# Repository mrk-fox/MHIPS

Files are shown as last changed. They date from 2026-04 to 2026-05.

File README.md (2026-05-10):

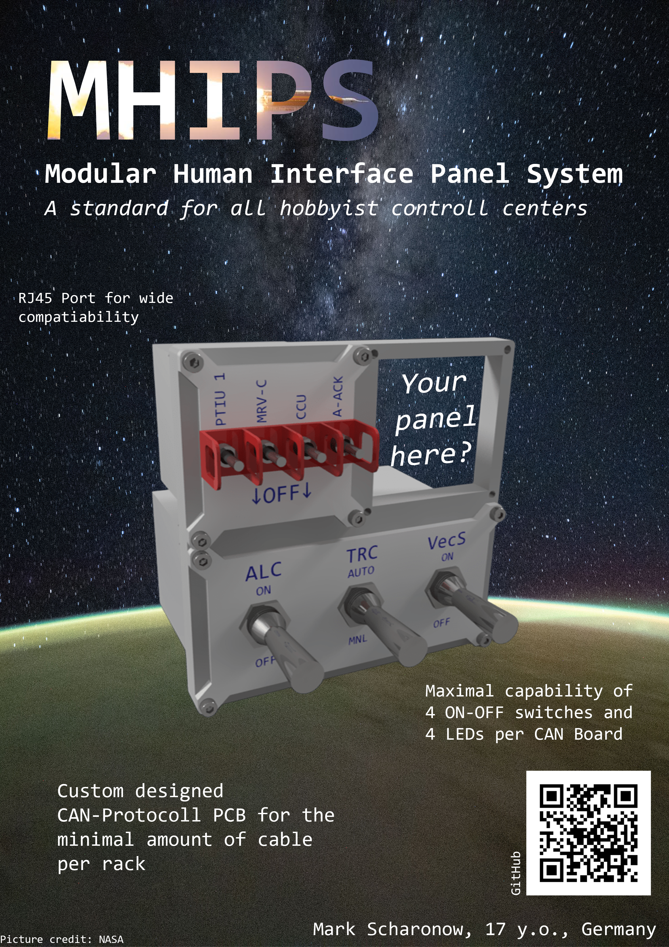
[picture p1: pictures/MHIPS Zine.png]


<h1 align="center">MHIPS</h1>
<div align="center">Modular Human Interface Panels System</div>
<br>
<div align="center">
      
 



</div>
<br>

<br> <br>
# Introduction
As controlling any type of craft with electronical components reqiring human intervention to function grows with the complexity of the craft and its tasks, I have decided to design a controlling system which is modular and uses near-aerospace-safety protocolls.

**Please pay attention to the fact that this project is still being developed. There is no "final solution" or such similar.**

## Functionality and goals

Every sucesfull project resembles a solution for a problem. Thus, the problem needs to be formulated before a solution is deigned. The problem that this project solves is the complexity of digital menus and the lack of haptic response in controlling anything with pure software.
My solution is a _modular, standartized panel system_ 
Hence, a ruleset was reqired to ensure the mulitcompatiability and extensiabiliy of this project.

### Why is it unique?
A central question in research, engineering and most other fields is "why has nobody done this before". Well, there are solutions to thes problem. Even one NASA provides in their GitHub repositories. But all of them are way to professional for amateur/non-professional use.

### Why did i make it?
Well, I'm planning on buiding an autonomous portable UAV someday. One day. Maybe. So these can be the GCC controls.

# Standartization

In this section we define a convention for the MHIPS (Modular Human Interface Panel System).
``` 
1. The abbreviation "MHIPS" stands for "Modular Human Interface Panel System".
      a. A panel is defined as a mounted and rigid resembly of multiple tiles, solving a user-defined task.
      b. A tile is defined as the smallest unit of the system. Any tile consists of the following components:
           b.1. A CAN-Capable read-write PCB as the BusPlate.
           b.2. A casing consisting of the front case and the backplate
           b.3. Input and output elements as Light Emitting Diodes, Buttons, Switches and more mounted into the front plate of the casing
      c. A rack is defined as the structure carrying and spacing the tiles.
2. The basic structure for a rack is a 5mm wide frame with the inner sizing of 50x50mm and a thickness of minimum 4mm. By fusing such frames togoether a rack is built. Each basic frame resembles the size of one unit (1U).
3. We define three levels of controll elements protection to ensure a dynamic range of application and environemntal adaptation.
      a. A level 3 tile is defined as a tile with no switch protection against accidental action.
      b. A level 2 tile is defined as a tile with sufficient control elements protection to ensure protection against accidental action. Only fully contacted switches (e.g.       ON-ON) are allowed.
      c. A level 1 tile is defined as a tile with maximal protection against accidental action. Double action is the minimum requirement. We split the level 1 category in the following subgroups:
            c.1. A level 1-S tile is definied as a tile meeting the basic level 1 requirements and the additional requirement of the maxiaml control element density of one control element per rack unit.
            c.2. A level 1-HV tile is definied as a tile meeting the basic level 1 requirements and additionally having the front tile face colored in a high visiability pattern (e.g. black and yellow stripes, 15mm wide at a 45° angle to the bottom plate of the tile) and having a maxiaml control element density of one control element per rack unit.
```
The given standartization is applied to all the racks and tiles in this current project.

# Example solution
In the following secion I will present my solution for the standartization and problem.

## BusPlate
The core piece of the work is the BusPlate resembling a PCB with the following features:

- RP2040 controller
- USB-C connectivity
- CAN Bus feature with MCP2515 controller
- Power and data over RJ45
- Decentralized computing capability on board

The following pictures are the front and back of the BusPlate PCB.

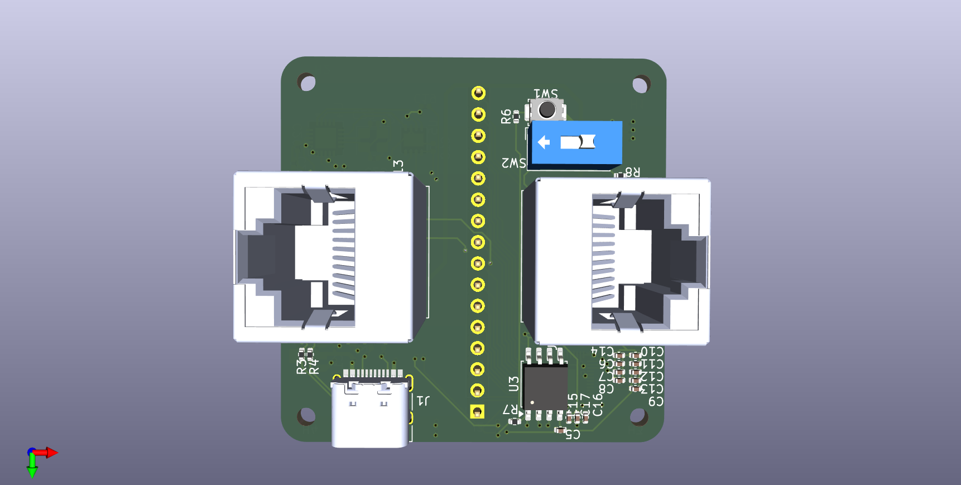
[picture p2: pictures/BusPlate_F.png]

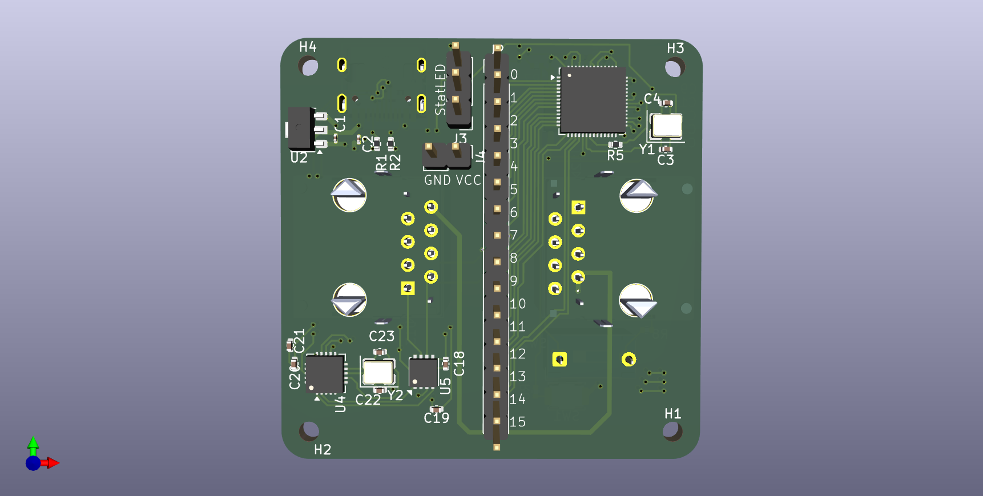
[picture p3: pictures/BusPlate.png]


The following diagram shows the schematics for this PCB created in KiCad.

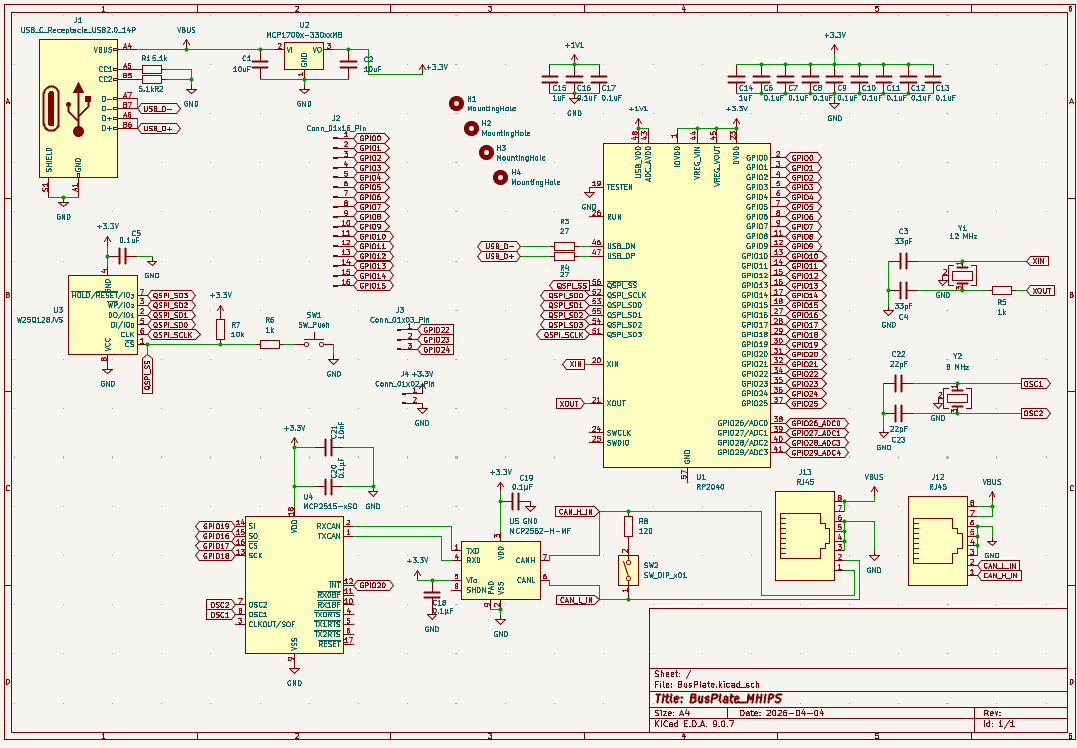
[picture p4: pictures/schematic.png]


The following picures are the single PCB layers in the order "Front, In 1, In 2, Back"

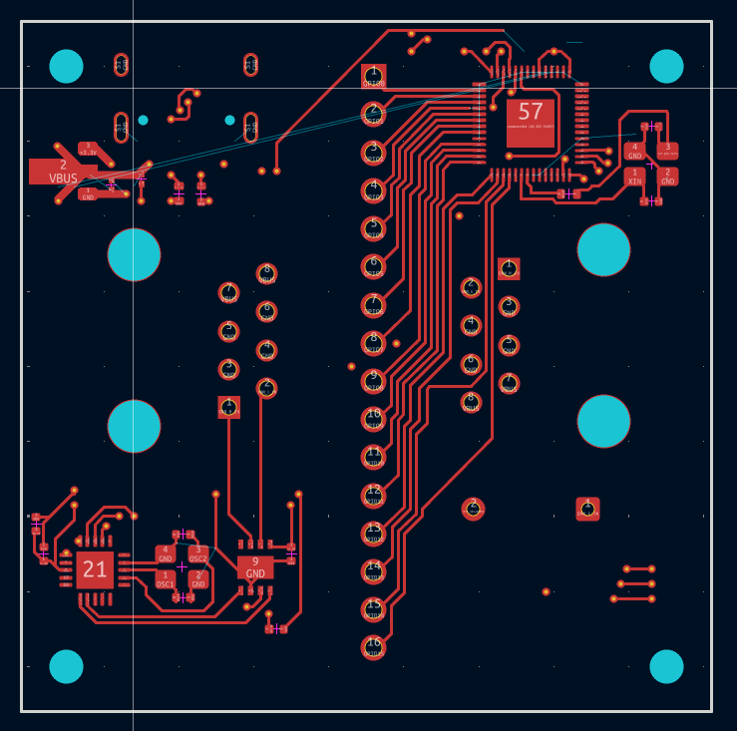
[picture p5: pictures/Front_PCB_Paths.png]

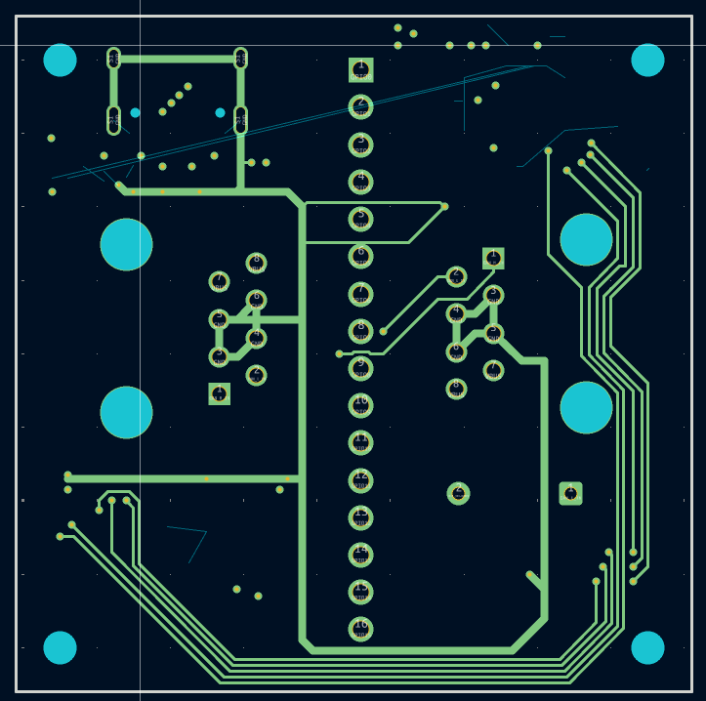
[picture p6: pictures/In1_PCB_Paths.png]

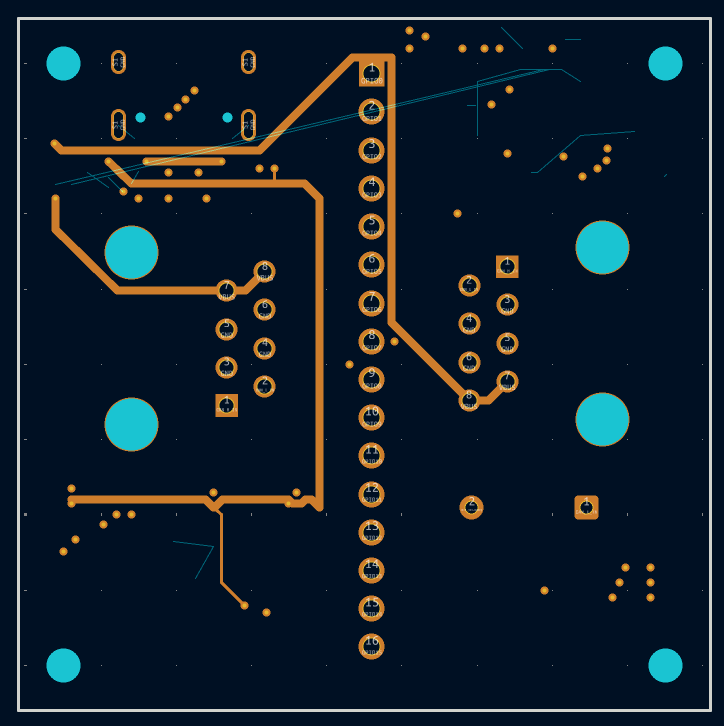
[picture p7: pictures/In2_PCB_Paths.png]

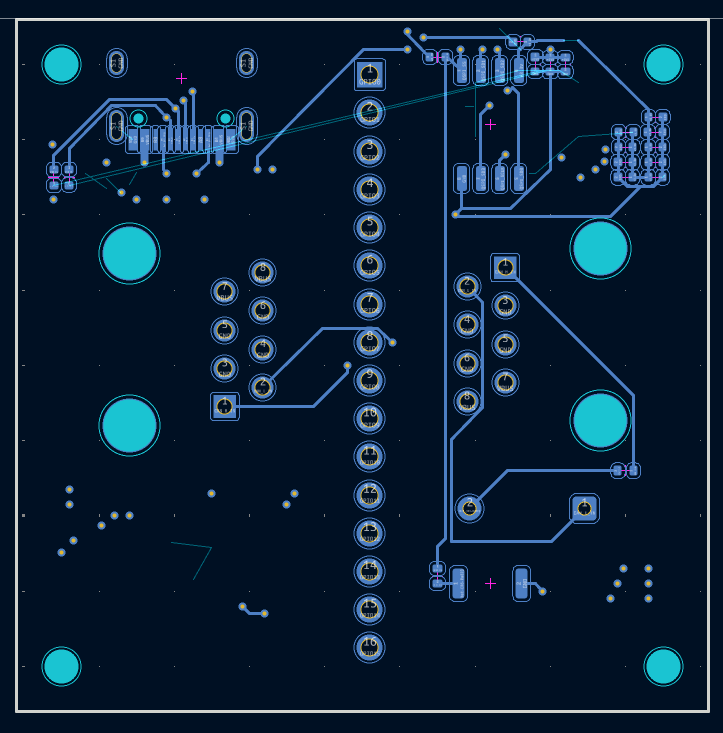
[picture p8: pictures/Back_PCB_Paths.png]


## Assembly
Now, the assembly is rather simple and I remind the reader that he or she has a free will, but here are some guidelines to get through this, sometimes messy, process in calm.
1. Solder female jumper wires to the elements.
2. Insert the elements into the main tile casing
3. Screw the treaded rods into the main casing.
4. Connect the controller PCB to the jumper wires.
5. Insert the PCB onto the spacers with the treads in the mounting holes.
6. Place the backplate onto the assembly and secure the rods with nuts.

Such and assembled tile looks then this way:

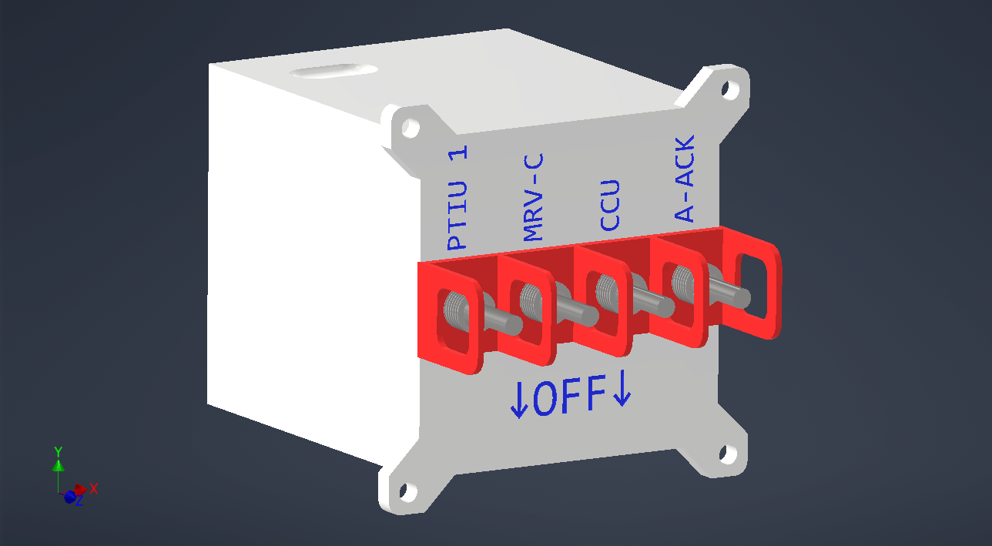
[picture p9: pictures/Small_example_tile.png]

Front
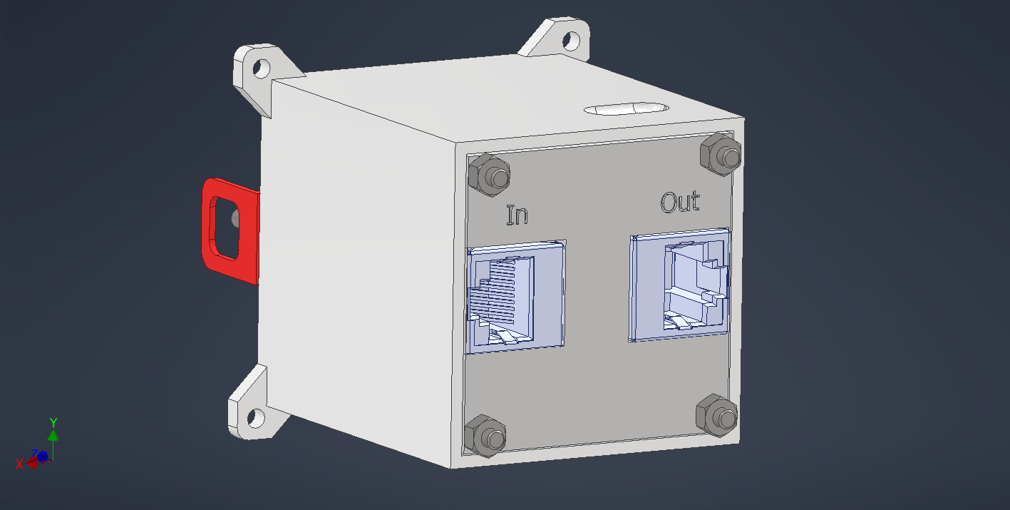
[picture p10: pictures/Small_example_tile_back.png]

Back

### Firmware
The firmware is the current biggest point of potential advance. Currently, there is a simple programm implemented which is able to get user input from state cahnges and forward it per CAN to all boards. This is sufficient for a simple read system to control basic tasks.

## Credit
I thank this project to... <br>
... [KiCad](https://www.kicad.org/)<br>
... [HackClub Fallout](https://fallout.hackclub.com/)<br>
... [Autodesk Inventor](https://www.autodesk.com/de/products/inventor/overview)<br>

## License

This hardware project is licensed under the **CERN Open Hardware Licence v2 - Strongly Reciprocal (CERN-OHL-S)**.

See the [LICENSE](./LICENSE) file for details, or visit https://ohwr.org/cern_ohl_s_v2.

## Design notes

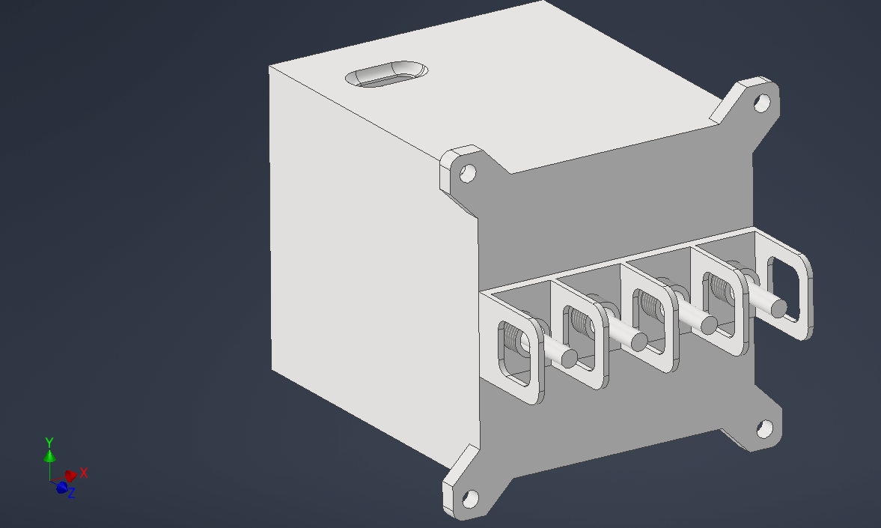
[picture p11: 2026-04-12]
pictures/1x1_lvl3_tile.png

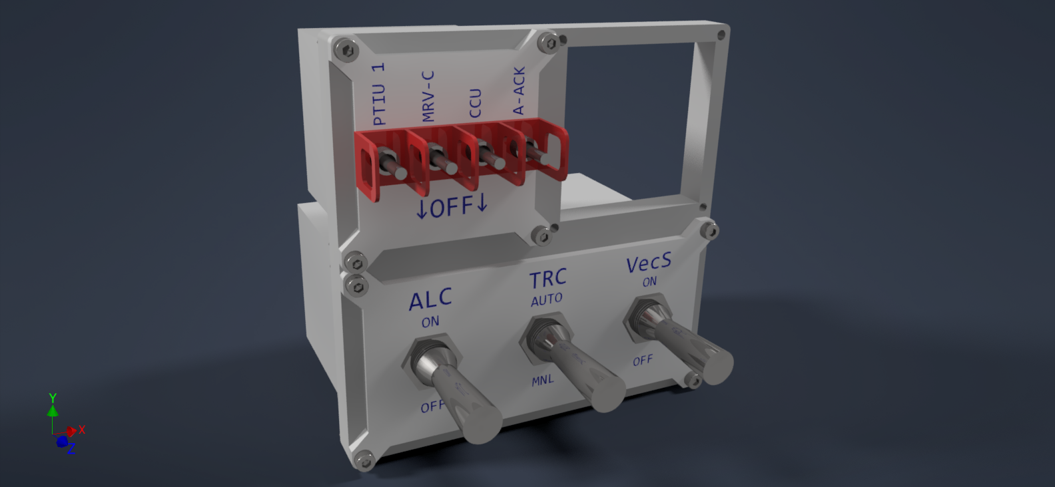
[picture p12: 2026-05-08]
pictures/demo_1.png

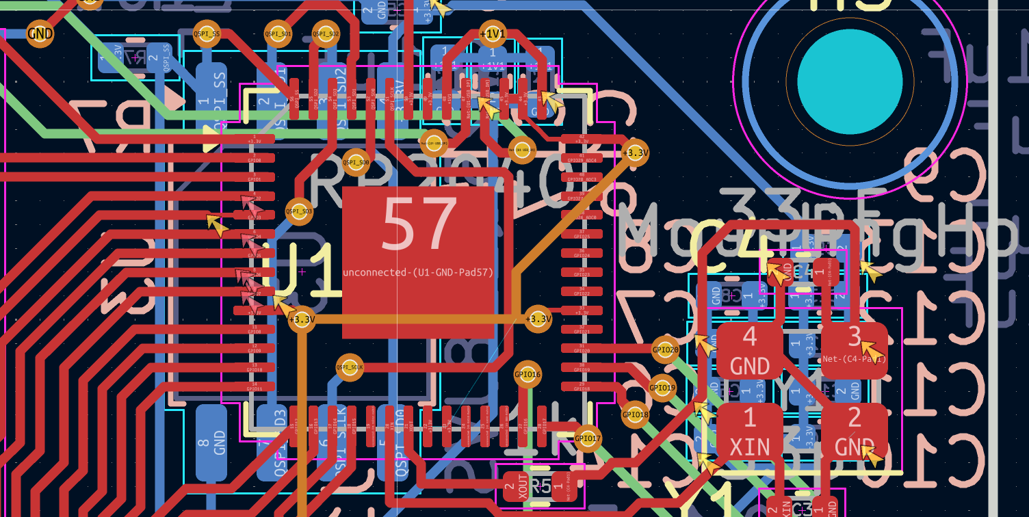
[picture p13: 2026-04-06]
pictures/RP2040_high_density.png

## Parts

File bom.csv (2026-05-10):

name | link | amount | price | running_sum
PCB | jlcpcb.com | 1 | 7.50 | 7.50
Switches | https://www.mouser.de/ProductDetail/Apem/5236CDB?qs=RNTjZpLRzVSCaQ8r2sKmHw%3D%3D | 4 | 17.40 | 24.9
Threaded M2 rods 55mm |  | 4
M2 Nut |  | 4
 |  |  | final_sum: | 24.9

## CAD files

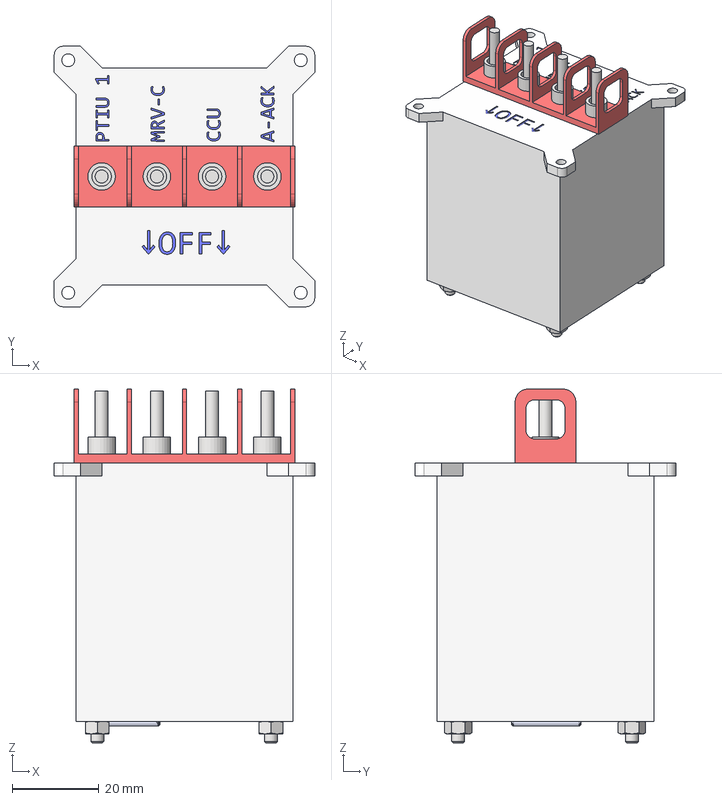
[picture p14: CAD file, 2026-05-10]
models/tiles/1x1/lvl301x01_4t/1x1_asm_main.stp
60.0 x 60.0 x 81.5 mm
casing_1x1_lvl3
APEM_5236CDB x 4
protector_small1x1
BusPlate
backplate
AS 1420 - 1973 - M3 x 20 x 4
ANSI B18.2.4.2M - M3x0,5 x 4

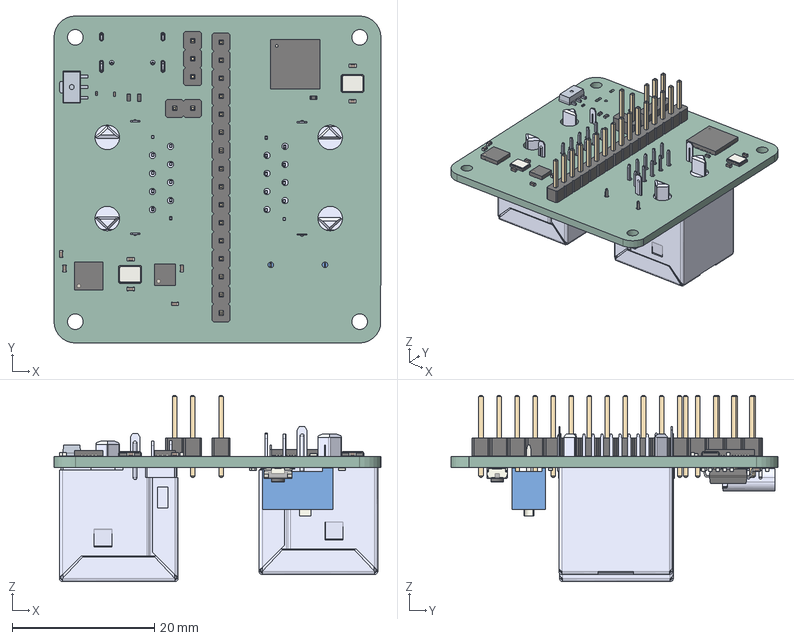
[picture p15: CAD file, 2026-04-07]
models/BusPlate/BusPlate.step
46.0 x 46.0 x 26.2 mm
R_0402_1005Metric x 8
PinHeader_1x16_P2.54mm_Vertical
C_0402_1005Metric x 21
BusPlate 1.5.1
QFN-56-1EP_7x7mm_P0.4mm_EP3.2x3.2mm
PinHeader_1x03_P2.54mm_Vertical
QFN-20-1EP_4x4mm_P0.5mm_EP2.5x2.5mm
DFN-8-1EP_3x3mm_P0.65mm_EP1.55x2.4mm
Crystal_SMD_3225-4Pin_3.2x2.5mm x 2
C_0201_0603Metric x 2
PinHeader_1x02_P2.54mm_Vertical
Same_Sky_UJ20-C-H-G-SMT-1-P16-TR
SW_DIP_SPSTx01_Slide_9.78x4.72mm_W7.62mm_P2.54mm
SW_Push_SPST_NO_Alps_SKRK
RJE741AA1110 x 2
SOIC-8_5.3x5.3mm_P1.27mm
BusPlate_PCB

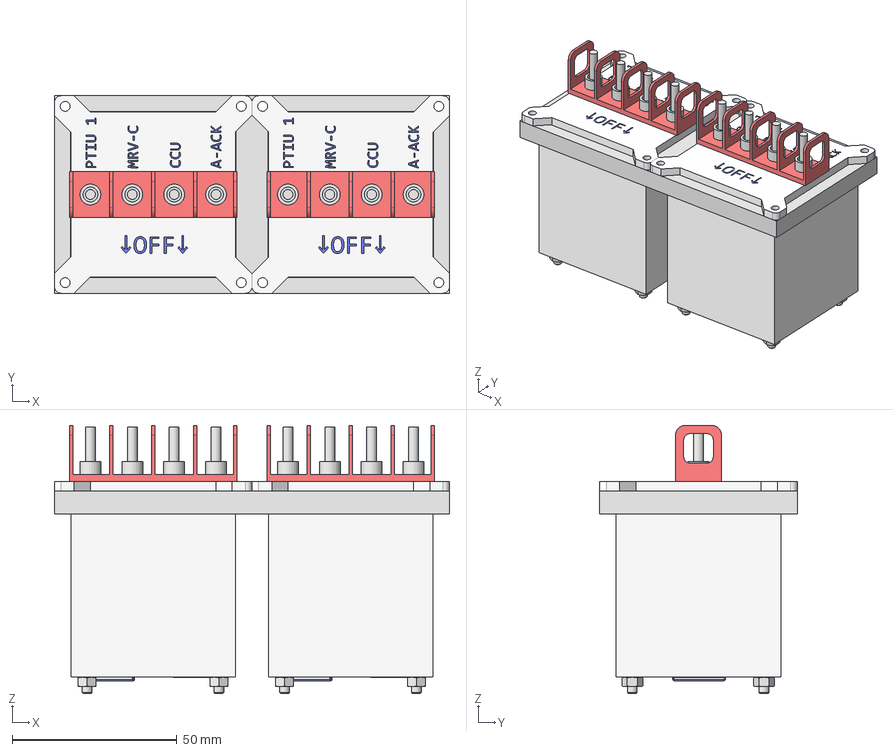
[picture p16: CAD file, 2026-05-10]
models/racks/assembled/rack_2x2_xy.stp
120.0 x 60.0 x 81.5 mm
rack_2x1
casing_1x1_lvl3 x 2
APEM_5236CDB x 8
protector_small1x1 x 2
BusPlate x 2
backplate x 2
AS 1420 - 1973 - M3 x 20 x 8
ANSI B18.2.4.2M - M3x0,5 x 8

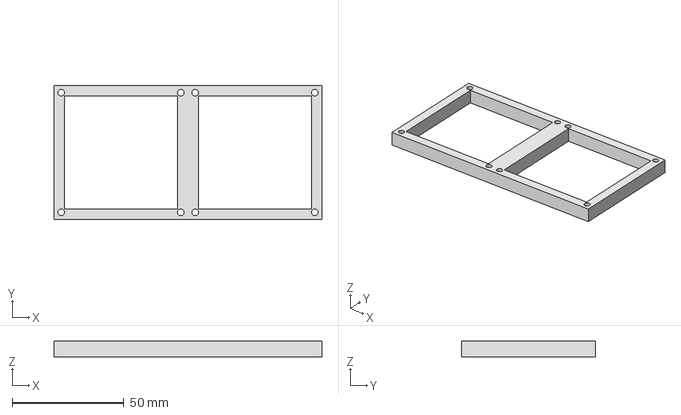
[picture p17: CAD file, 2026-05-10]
models/racks/frames/rack_2x1.stp
120.0 x 60.0 x 7.00 mm

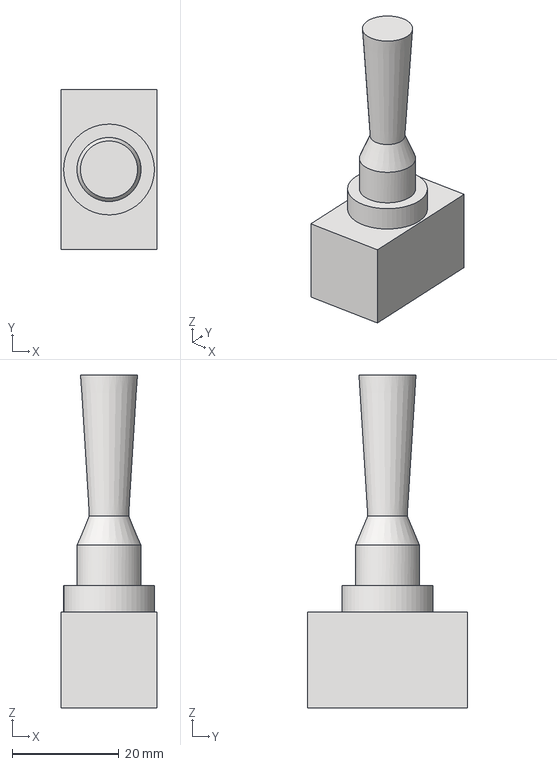
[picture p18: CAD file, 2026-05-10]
models/switches/NKK_S1AL.stp
18.0 x 30.0 x 62.4 mm

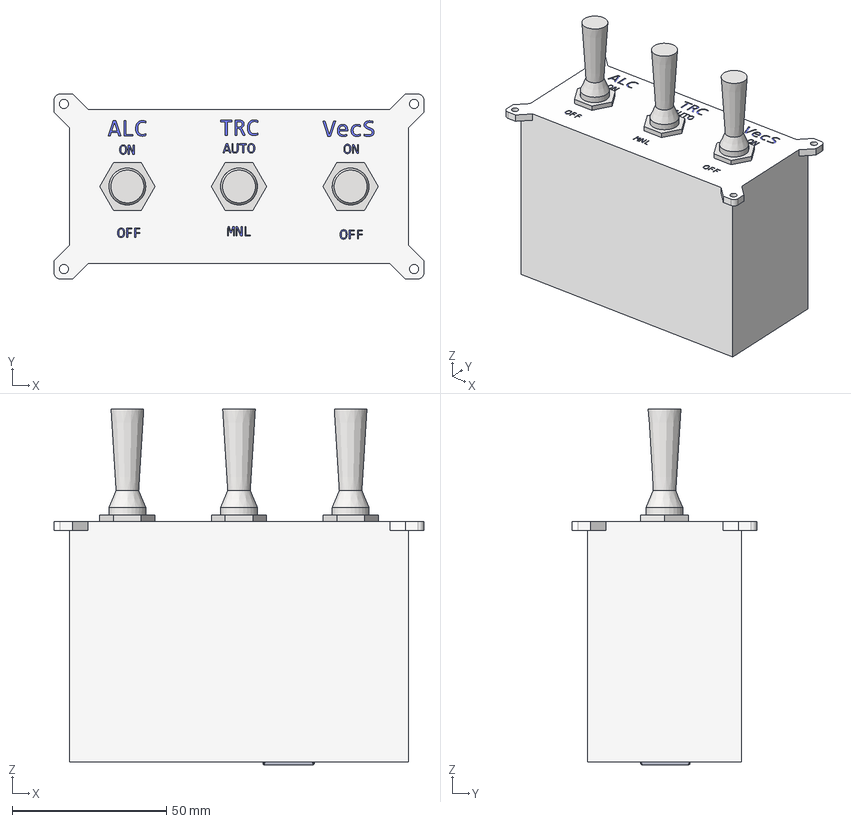
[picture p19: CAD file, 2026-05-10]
models/tiles/2x1/lvl202x01_t/lvl202x01.stp
120.0 x 60.0 x 115.4 mm
lvl202x01_toggle_body
NKK_S1AL x 3
R_0402_1005Metric x 8
PinHeader_1x16_P2.54mm_Vertical
C_0402_1005Metric x 21
BusPlate 1.5.1
QFN-56-1EP_7x7mm_P0.4mm_EP3.2x3.2mm
PinHeader_1x03_P2.54mm_Vertical
QFN-20-1EP_4x4mm_P0.5mm_EP2.5x2.5mm
DFN-8-1EP_3x3mm_P0.65mm_EP1.55x2.4mm
Crystal_SMD_3225-4Pin_3.2x2.5mm x 2
C_0201_0603Metric x 2
PinHeader_1x02_P2.54mm_Vertical
Same_Sky_UJ20-C-H-G-SMT-1-P16-TR
SW_DIP_SPSTx01_Slide_9.78x4.72mm_W7.62mm_P2.54mm
SW_Push_SPST_NO_Alps_SKRK
RJE741AA1110 x 2
SOIC-8_5.3x5.3mm_P1.27mm
BusPlate_PCB
backplate_lvl202x01
NKK_S1AL_mother x 3

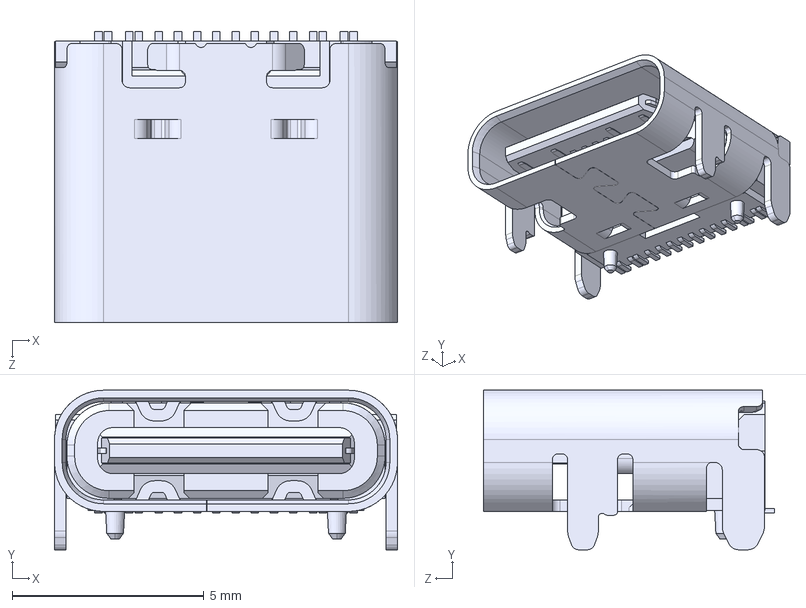
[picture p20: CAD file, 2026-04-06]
pcb/BusPlate/pcb_cad/Same_Sky_UJ20-C-H-G-SMT-1-P16-TR.step
8.94 x 4.16 x 7.60 mm

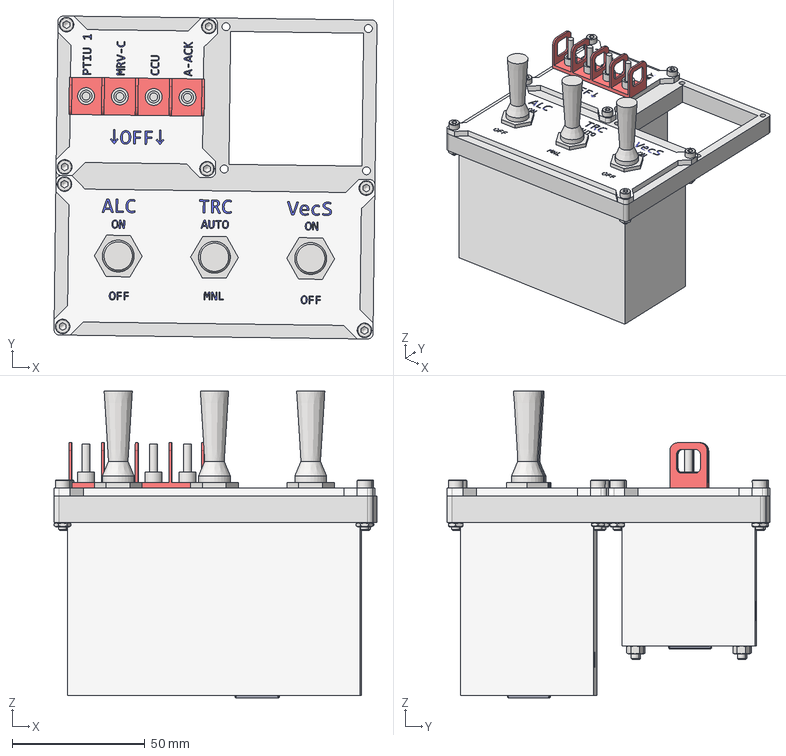
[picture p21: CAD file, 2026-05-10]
models/racks/assembled/demo_1.stp
121.5 x 121.5 x 115.4 mm
lvl202x01_toggle_body
NKK_S1AL x 3
R_0402_1005Metric x 8
PinHeader_1x16_P2.54mm_Vertical
C_0402_1005Metric x 21
BusPlate 1.5.1
QFN-56-1EP_7x7mm_P0.4mm_EP3.2x3.2mm
PinHeader_1x03_P2.54mm_Vertical
QFN-20-1EP_4x4mm_P0.5mm_EP2.5x2.5mm
DFN-8-1EP_3x3mm_P0.65mm_EP1.55x2.4mm
Crystal_SMD_3225-4Pin_3.2x2.5mm x 2
C_0201_0603Metric x 2
PinHeader_1x02_P2.54mm_Vertical
Same_Sky_UJ20-C-H-G-SMT-1-P16-TR
SW_DIP_SPSTx01_Slide_9.78x4.72mm_W7.62mm_P2.54mm
SW_Push_SPST_NO_Alps_SKRK
RJE741AA1110 x 2
SOIC-8_5.3x5.3mm_P1.27mm
BusPlate_PCB
backplate_lvl202x01
NKK_S1AL_mother x 3
casing_1x1_lvl3
APEM_5236CDB x 4
protector_small1x1
BusPlate
backplate
AS 1420 - 1973 - M3 x 20 x 4
ANSI B18.2.4.2M - M3x0,5 x 4
frame_demo_2x2_xyxx
AS 1420 - 1973 - M3 x 16 x 8
DIN 439 - M3 x 7
DIN 439 - M2,5

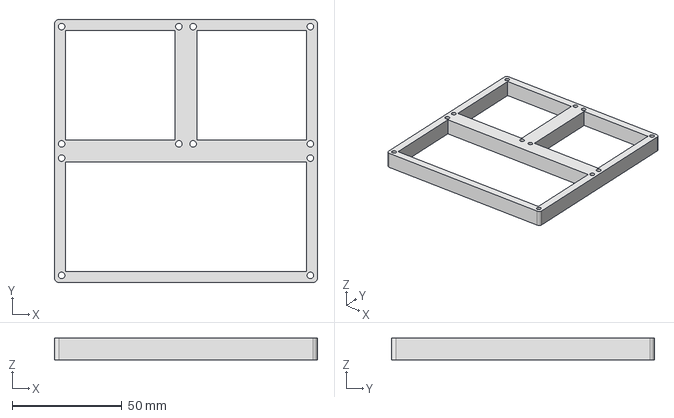
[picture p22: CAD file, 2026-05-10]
models/racks/frames/frame_demo_2x2_xyxx.stp
120.0 x 120.0 x 10.0 mm

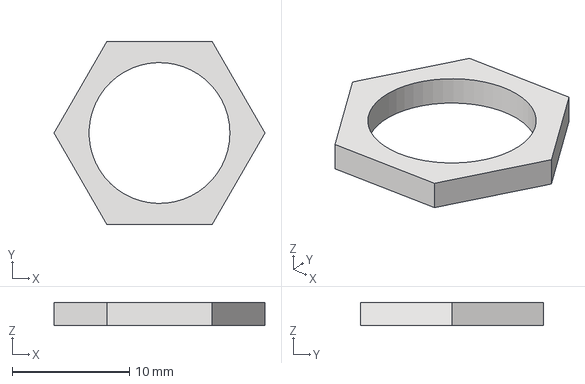
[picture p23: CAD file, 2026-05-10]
models/switches/NKK_S1AL_mother.stp
18.0 x 15.6 x 2.00 mm

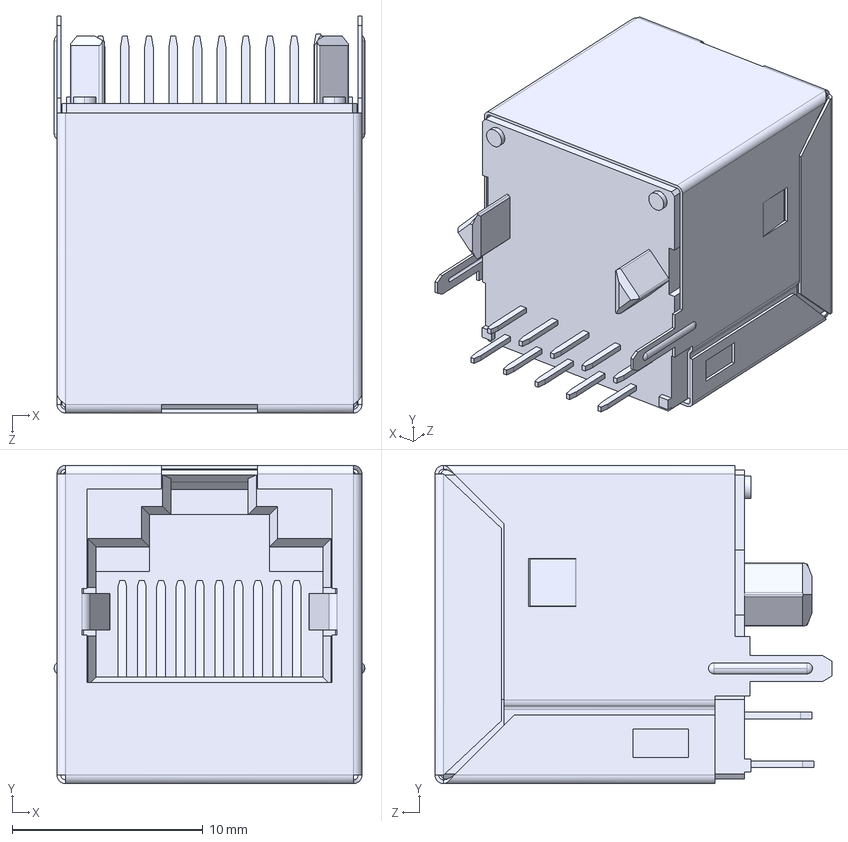
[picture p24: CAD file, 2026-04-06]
pcb/BusPlate/pcb_cad/RJE741AA1110.STEP
16.3 x 16.7 x 20.8 mm

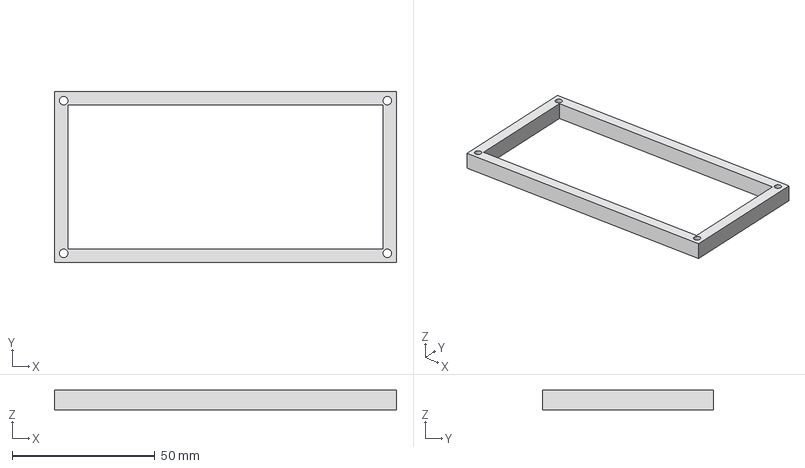
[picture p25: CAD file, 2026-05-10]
models/racks/frames/rack_C2x1.stp
120.0 x 60.0 x 7.00 mm

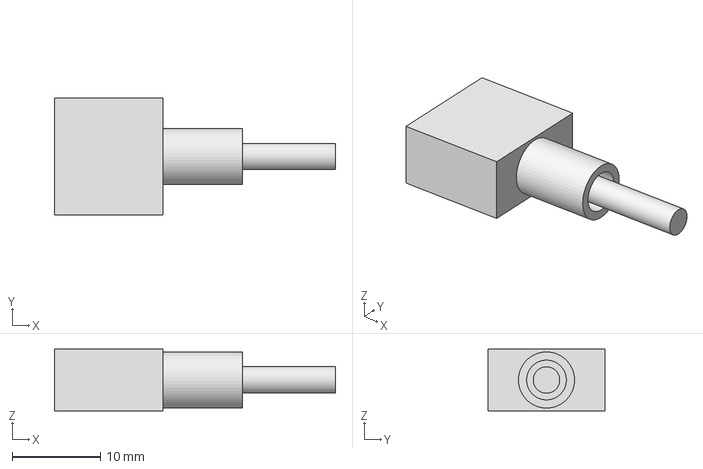
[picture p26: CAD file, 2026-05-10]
models/switches/APEM_5236CDB.stp
31.8 x 13.2 x 7.00 mm

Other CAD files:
models/BusPlate/BusPlate 1.5.1.ipt
models/BusPlate/BusPlate.iam
models/BusPlate/BusPlate.ipt
models/BusPlate/BusPlate_PCB.ipt
models/BusPlate/C_0201_0603Metric.ipt
models/BusPlate/C_0402_1005Metric.ipt
models/BusPlate/Crystal_SMD_3225-4Pin_3.2x2.5mm.ipt
models/BusPlate/DFN-8-1EP_3x3mm_P0.65mm_EP1.55x2.4mm.ipt
models/BusPlate/OldVersions/BusPlate.0001.ipt
models/BusPlate/PinHeader_1x02_P2.54mm_Vertical.ipt
models/BusPlate/PinHeader_1x03_P2.54mm_Vertical.ipt
models/BusPlate/PinHeader_1x16_P2.54mm_Vertical.ipt
models/BusPlate/QFN-20-1EP_4x4mm_P0.5mm_EP2.5x2.5mm.ipt
models/BusPlate/QFN-56-1EP_7x7mm_P0.4mm_EP3.2x3.2mm.ipt
models/BusPlate/RJE741AA1110.ipt
models/BusPlate/R_0402_1005Metric.ipt
models/BusPlate/SOIC-8_5.3x5.3mm_P1.27mm.ipt
models/BusPlate/SOT-89-3.iam
models/BusPlate/SW_DIP_SPSTx01_Slide_9.78x4.72mm_W7.62mm_P2.54mm.ipt
models/BusPlate/SW_Push_SPST_NO_Alps_SKRK.ipt
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

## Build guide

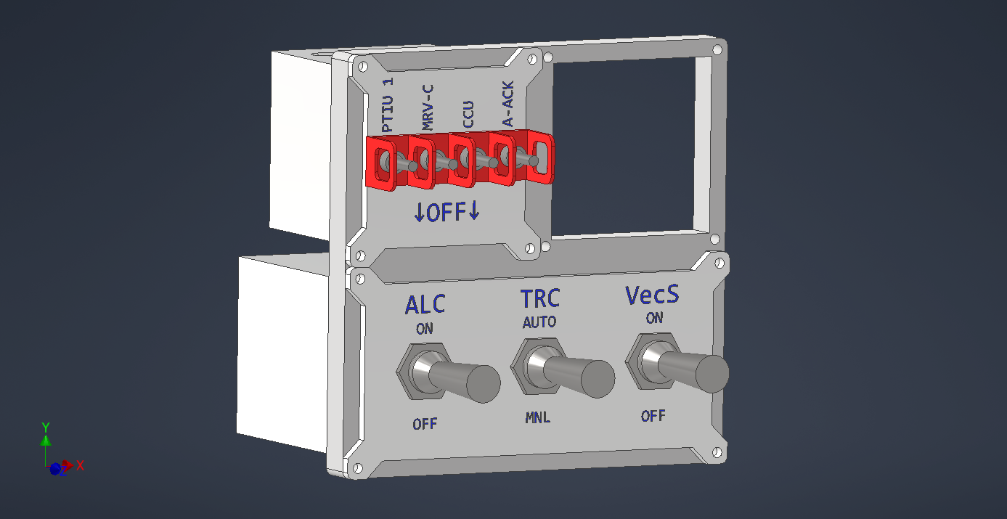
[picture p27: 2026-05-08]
pictures/example assembly.png

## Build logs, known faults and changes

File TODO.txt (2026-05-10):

- Create DLNS - Data Log Node Segment
	Features:
		-Registers CAN bus and gives log on current ground sys state (Writing to a diffrent DB)
		-Forms CAN Bus stream into I/O states
		-Compares raw input to real action table
		-Writes action/todo to local Database
	Question: Where does the task-to-action computing happen? On board?
	
	Format: Vertical rack as all processing units???
	
	Raspberry Pi w/ CAN hat. Workflow is CAN sw.addr. -> Actions Table -> LAN Database upload.
	Format: Rack, vertical with expansion room.

- Create the following tiles:
	3lvl01x01-4xon-off_sw
	3lvl01x02-8xoff-(on)_btn+1:1led_ind
	2lvl02x01-locking (AP select panel)
	1lvl-s01x01

create one panel assembly	

- DOCUMENTATION
	In it...
		... standart sizes+norms
		... one full panel 
		... terminology

->MHIPS->Panels->Tiles->Controll blocks
		      ->Processing

Firmware

setup: 
	define slave/master
	define address
	init SPI/MCP
	init button config
	init 

loop:
	Is any button pressed?
		yes: send button address and action
	Is anything recieved?
		yes: analyse data and write

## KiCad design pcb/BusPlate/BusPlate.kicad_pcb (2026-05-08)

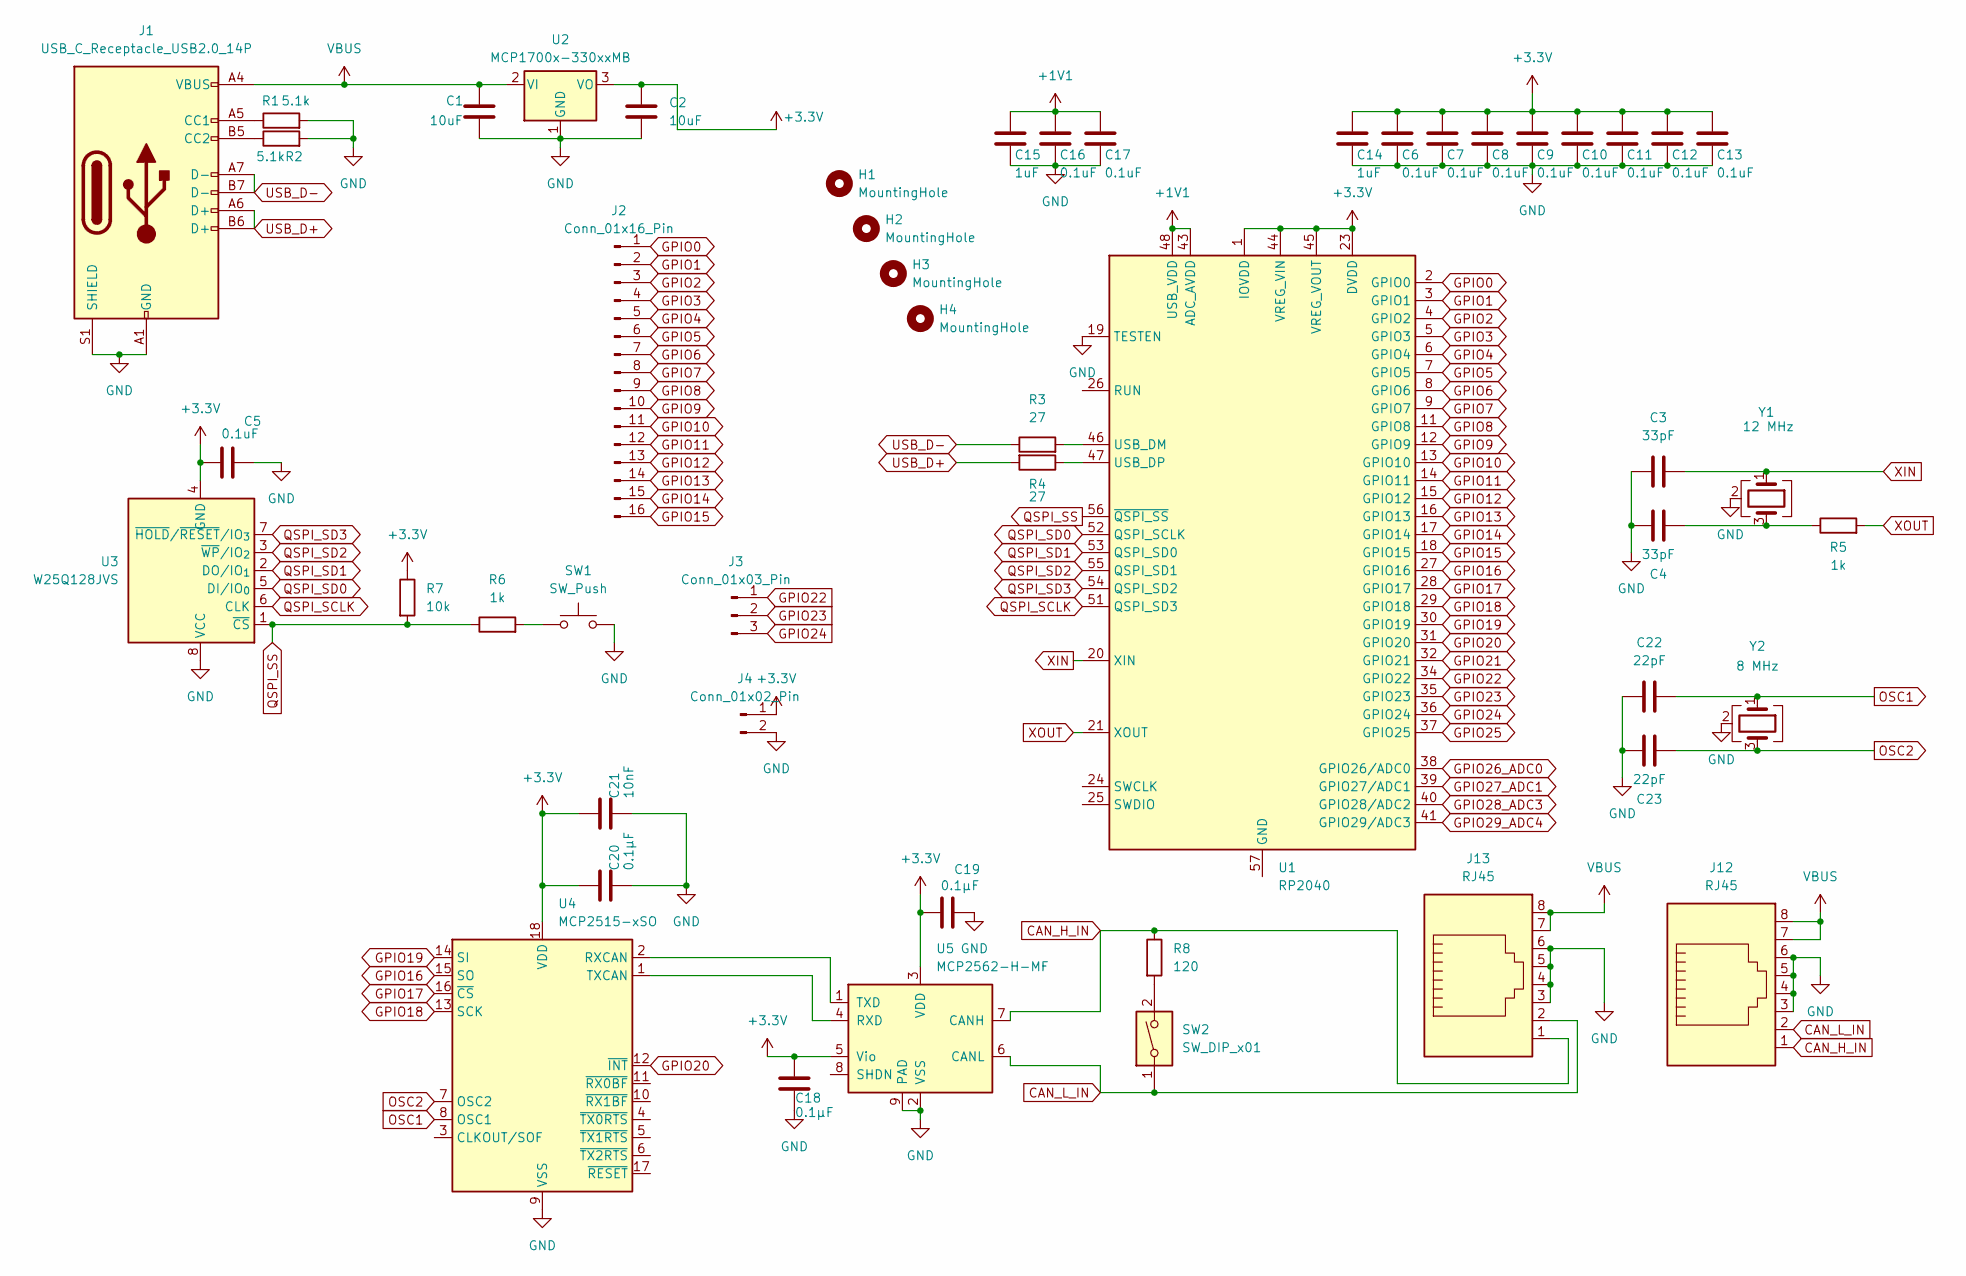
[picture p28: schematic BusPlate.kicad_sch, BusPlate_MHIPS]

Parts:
C1, C2: 10uF; C_0201_0603Metric
C3, C4: 33pF; C_0402_1005Metric
C5, C6, C7, C8, C9, C10, C11, C12, C13, C16, C17: 0.1uF; C_0402_1005Metric
C14, C15: 1uF; C_0402_1005Metric
C18, C19, C20: 0.1µF; C_0402_1005Metric
C21: 10nF; C_0402_1005Metric
C22, C23: 22pF; C_0402_1005Metric
H1, H2, H3, H4: MountingHole; MountingHole_2.2mm_M2
J1: USB_C_Receptacle_USB2.0_14P; USB_C_Receptacle_HRO_TYPE-C-31-M-12
J2: Conn_01x16_Pin; PinHeader_1x16_P2.54mm_Vertical
J3: Conn_01x03_Pin; PinHeader_1x03_P2.54mm_Vertical
J4: Conn_01x02_Pin; PinHeader_1x02_P2.54mm_Vertical
J12, J13: RJ45; RJ45_OST_PJ012-8P8CX_Vertical
R1, R2: 5.1k; R_0402_1005Metric
R3, R4: 27; R_0402_1005Metric
R5, R6: 1k; R_0402_1005Metric
R7: 10k; R_0402_1005Metric
R8: 120; R_0402_1005Metric
SW1: SW_Push; SW_Push_SPST_NO_Alps_SKRK
SW2: SW_DIP_x01; SW_DIP_SPSTx01_Slide_9.78x4.72mm_W7.62mm_P2.54mm
U1: RP2040; QFN-56-1EP_7x7mm_P0.4mm_EP3.2x3.2mm
U2: MCP1700x-330xxMB; SOT-89-3
U3: W25Q128JVS; SOIC-8_5.3x5.3mm_P1.27mm
U4: MCP2515-xSO; QFN-20-1EP_4x4mm_P0.5mm_EP2.5x2.5mm
U5: MCP2562-H-MF; DFN-8-1EP_3x3mm_P0.65mm_EP1.55x2.4mm
Y1: 12 MHz; Crystal_SMD_3225-4Pin_3.2x2.5mm
Y2: 8 MHz; Crystal_SMD_3225-4Pin_3.2x2.5mm

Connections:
+1V1: C15.1, C16.1, C17.1, U1.43 (ADC_AVDD), U1.48 (USB_VDD)
+3.3V: C2.1, C5.1, C6.1, C7.1, C8.1, C9.1, C10.1, C11.1, C12.1, C13.1, C14.1, C18.1, C19.1, C20.1, C21.1, J4.1, R7.1, U1.1 (IOVDD), U1.10 (IOVDD), U1.22 (IOVDD), U1.23 (DVDD), U1.33 (IOVDD), U1.42 (IOVDD), U1.44 (VREG_VIN), U1.45 (VREG_VOUT), U1.49 (IOVDD), U1.50 (DVDD), U2.3 (VO), U3.4 (GND), U4.18 (VDD), U5.3 (VDD), U5.5 (Vio)
CAN_H_IN: J12.1, J13.1, R8.1, U5.7 (CANH)
CAN_L_IN: J12.2, J13.2, SW2.1, U5.6 (CANL)
GND: C1.2, C2.2, C3.1, C4.2, C5.2, C6.2, C7.2, C8.2, C9.2, C10.2, C11.2, C12.2, C13.2, C14.2, C15.2, C16.2, C17.2, C18.2, C19.2, C20.2, C21.2, C22.1, C23.2, J1.A1 (GND), J1.A12 (GND), J1.B1 (GND), J1.B12 (GND), J1.S1 (SHIELD), J4.2, J12.3, J12.4, J12.5, J12.6, J13.3, J13.4, J13.5, J13.6, R1.2, R2.2, SW1.2, U1.19 (TESTEN), U2.1 (GND), U3.8 (VCC), U4.9 (VSS), U5.2 (VSS), U5.9 (PAD), Y1.2 (G), Y1.4 (G), Y2.2 (G), Y2.4 (G)
GPIO0: J2.1, U1.2 (GPIO0)
GPIO1: J2.2, U1.3 (GPIO1)
GPIO2: J2.3, U1.4 (GPIO2)
GPIO3: J2.4, U1.5 (GPIO3)
GPIO4: J2.5, U1.6 (GPIO4)
GPIO5: J2.6, U1.7 (GPIO5)
GPIO6: J2.7, U1.8 (GPIO6)
GPIO7: J2.8, U1.9 (GPIO7)
GPIO8: J2.9, U1.11 (GPIO8)
GPIO9: J2.10, U1.12 (GPIO9)
GPIO10: J2.11, U1.13 (GPIO10)
GPIO11: J2.12, U1.14 (GPIO11)
GPIO12: J2.13, U1.15 (GPIO12)
GPIO13: J2.14, U1.16 (GPIO13)
GPIO14: J2.15, U1.17 (GPIO14)
GPIO15: J2.16, U1.18 (GPIO15)
GPIO16: U1.27 (GPIO16), U4.15 (SO)
GPIO17: U1.28 (GPIO17), U4.16 (~CS)
GPIO18: U1.29 (GPIO18), U4.13 (SCK)
GPIO19: U1.30 (GPIO19), U4.14 (SI)
GPIO20: U1.31 (GPIO20), U4.12 (~INT)
GPIO21: U1.32 (GPIO21)
GPIO22: J3.1, U1.34 (GPIO22)
GPIO23: J3.2, U1.35 (GPIO23)
GPIO24: J3.3, U1.36 (GPIO24)
GPIO25: U1.37 (GPIO25)
GPIO26_ADC0: U1.38 (GPIO26/ADC0)
GPIO27_ADC1: U1.39 (GPIO27/ADC1)
GPIO28_ADC3: U1.40 (GPIO28/ADC2)
GPIO29_ADC4: U1.41 (GPIO29/ADC3)
unnamed: C4.1, R5.1, Y1.3
unnamed: J1.A5 (CC1), R1.1
unnamed: J1.B5 (CC2), R2.1
unnamed: R6.2, SW1.1
unnamed: R8.2, SW2.2
unnamed: R3.2, U1.46 (USB_DM)
unnamed: R4.1, U1.47 (USB_DP)
unnamed: U4.2 (RXCAN), U5.1 (TXD)
unnamed: U4.1 (TXCAN), U5.4 (RXD)
OSC1: C22.2, U4.8 (OSC1), Y2.1
OSC2: C23.1, U4.7 (OSC2), Y2.3
QSPI_SCLK: U1.51 (QSPI_SD3), U3.6 (CLK)
QSPI_SD0: U1.52 (QSPI_SCLK), U3.5 (DI/IO_{0})
QSPI_SD1: U1.53 (QSPI_SD0), U3.2 (DO/IO_{1})
QSPI_SD2: U1.55 (QSPI_SD1), U3.3 (~WP/IO_{2})
QSPI_SD3: U1.54 (QSPI_SD2), U3.7 (~HOLD/~RESET/IO_{3})
QSPI_SS: R6.1, R7.2, U1.56 (~QSPI_SS), U3.1 (~CS)
USB_D+: J1.A6 (D+), J1.B6 (D+), R4.2
USB_D-: J1.A7 (D-), J1.B7 (D-), R3.1
VBUS: C1.1, J1.A4 (VBUS), J1.A9 (VBUS), J1.B4 (VBUS), J1.B9 (VBUS), J12.7, J12.8, J13.7, J13.8, U2.2 (VI)
XIN: C3.2, U1.20 (XIN), Y1.1
XOUT: R5.2, U1.21 (XOUT)

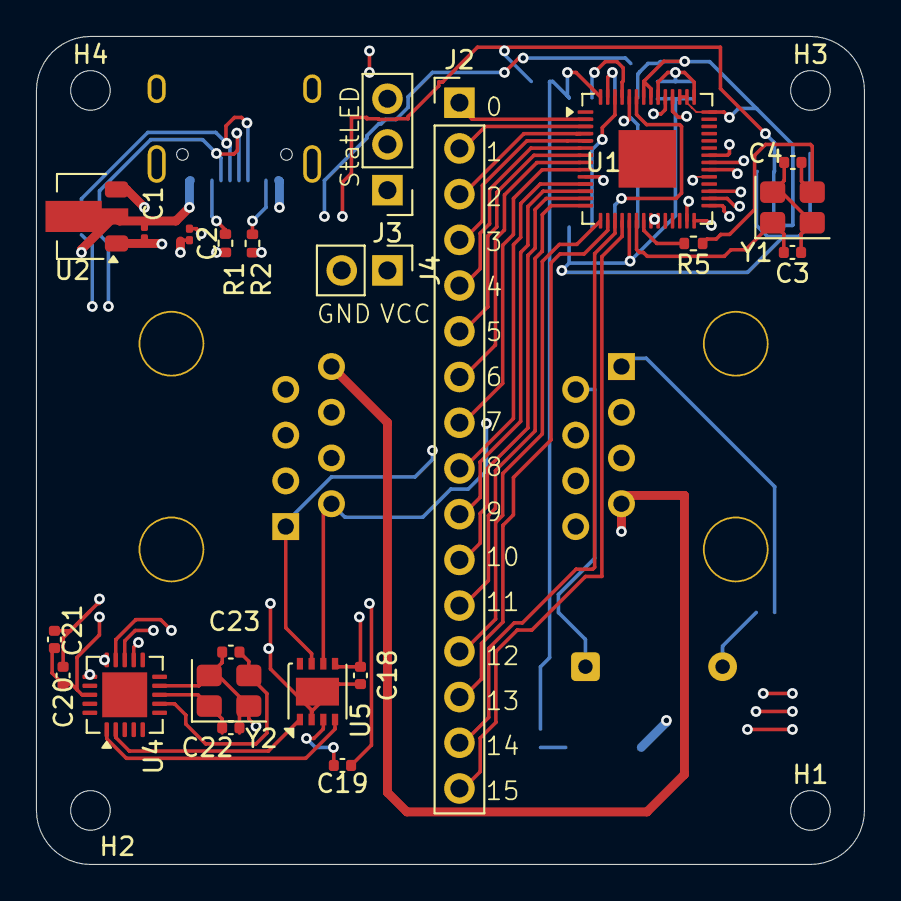
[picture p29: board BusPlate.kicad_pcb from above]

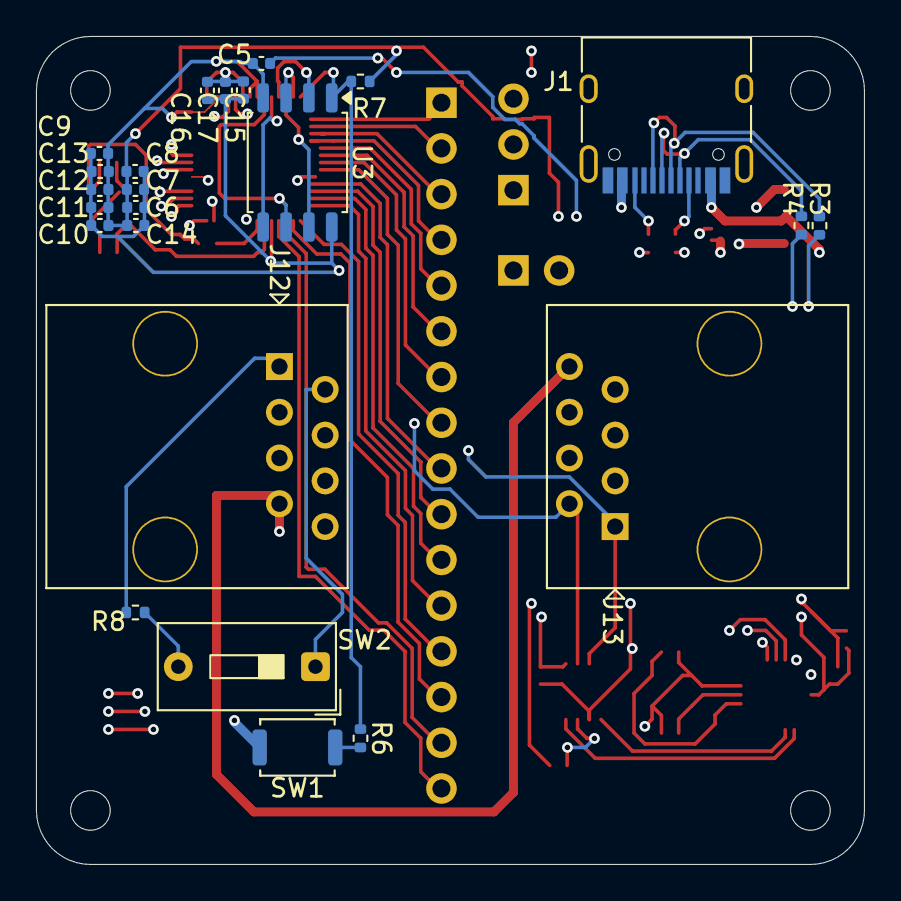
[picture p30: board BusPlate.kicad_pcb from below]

Board: 4 copper layers, 46.0 x 46.0 mm, 50 parts (24 on the bottom side), 51 nets.

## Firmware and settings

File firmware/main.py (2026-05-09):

# use https://github.com/Longan-Labs/MicroPython_CAN_BUS_MCP2515 for CAN bus support
import sys
import time
from machine import Pin
from canbus import Can, CanError, CanMsg, CanMsgFlag

id = 0x002

id_byte_high = (id >> 8) & 0xFF
id_byte_low  = id & 0xFF 

setup_array = [Pin.IN, Pin.IN, Pin.IN, Pin.IN, Pin.IN, Pin.IN, Pin.IN, Pin.IN, Pin.IN, Pin.IN, Pin.IN, Pin.IN, Pin.IN, Pin.IN, Pin.IN, Pin.IN]
pin_addr_array = [0x01, 0x02, 0x03, 0x04, 0x05, 0x06, 0x07, 0x08, 0x09, 0x0A, 0x0B, 0x0C, 0x0D, 0x0E, 0x0F, 0x10]
states_array = [0, 0, 0, 0, 0, 0, 0, 0, 0, 0, 0, 0, 0, 0, 0, 0]
pin_array = [p0, p1, p2, p3, p4, p5, p6, p7, p8, p9, p10, p11, p12, p13, p14, p15]


can = Can()
error = can.begin()
if error != CanError.ERROR_OK:
    print("Failed to initialize can!")


p0 = Pin(2, setup_array[0])
p1 = Pin(3, setup_array[1])
p2 = Pin(4, setup_array[2])
p3 = Pin(5, setup_array[3])
p4 = Pin(6, setup_array[4])
p5 = Pin(7, setup_array[5])
p6 = Pin(8, setup_array[6])
p7 = Pin(9, setup_array[7])
p8 = Pin(11, setup_array[8])
p9 = Pin(12, setup_array[9])
p10 = Pin(13, setup_array[10])
p11 = Pin(14, setup_array[11])
p12 = Pin(15, setup_array[12])
p13 = Pin(16, setup_array[13])
p14 = Pin(17, setup_array[14])
p15 = Pin(18, setup_array[15])


for i in range(0, 16):
    read = pin_array[i].value()
    states_array[i] = read

while True:
    for i in range(0, 16):
        read = pin_array[i].value()
        if read != states_array[i]:
            states_array[i] = read
            msg = CanMsg(can_id=id, data=b"\x01\id_byte_high\id_byte_low\x00\x00\x00\x00\pin_addr_array[i]")
            error = can.send(msg)
            if error != CanError.ERROR_OK:
                print("Failed to send!")
    if can.checkReceive():
        error, msg = can.recv()
        if error == CanError.ERROR_OK:
            print("Can id", msg.can_id)
            print("Can data", msg.data)
    time.sleep(0.1)

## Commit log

2026-04-05 First PCB design completed, set rules for modularity
    [2x1_LEVEL-2_Panel.kicad_pcb, 2x1_LEVEL-2_Panel.kicad_sch, BusPlate.kicad_pcb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]
2026-04-06 Ready first PCB
    [BusPlate.kicad_pcb, BusPlate.step, RJE741AA1110.STEP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]
2026-04-07 Further rack and PCB development
    [02x01U_2lvl301x01.0001.iam, 02x01U_2lvl301x01.iam, 1x1_asm_main.0005.iam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]
2026-04-12 Add BusPlate models, update PCB & reorganize tiles
    Add a collection of BusPlate 3D/part models and a tile PNG, reorganize several model assemblies into lvl301x01_4t/OldVersions, and update switch model versioning. Adjust KiCad board files (BusPlate.kicad_pcb edge cuts geometry, active layer in .kicad_prl) and fix the step export path in .kicad_pro. Add BusPlate PCB backup archives and update test assemblies. Small docs updates: note about LtSpice in PLANNING.txt and Raspberry Pi/CAN workflow in TODO.txt to reflect the intended hardware/software approach.
    [02x01U_2lvl301x01.0001.iam, 02x01U_2lvl301x01.0002.iam, 02x01U_2lvl301x01.iam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]
2026-05-08 Add PCB files, models, tiles, and BOM
    Add BOM.csv and multiple project assets: KiCad PCB and Gerber outputs for BusPlate (including backups and .zip), update BusPlate.kicad_pcb, and add example pictures. Add and reorganize numerous CAD m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
    [02x01U_2lvl301x01.0002.iam, 02x01U_2lvl301x01.iam, 1x1_asm_main.0006.iam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]
2026-05-10 Add KiCad lockfile, update TODO and image
    Expanded TODO.txt with firmware notes and a basic setup/loop flow (define master/slave and addresses, init SPI/MCP and buttons, handle button presses and incoming data). Added pcb/BusPlate/~BusPlate.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
2026-05-10 Update README with detailed component definitions
    Expanded definitions for tiles, racks, and control levels. Added details about the BusPlate and included images of the PCB layers.
2026-05-10 Enhance README with project badges and new sections
    Added badges for KiCad, Espressif, and AutoDesk, and included sections on uniqueness and motivation for the project.
2026-05-10 Add backplate version, update backplate and image
    Add an OldVersions copy of the backplate IPT, replace/update the main backplate IPT binary, add a small example tile back PNG, and remove a transient KiCad PCB lock file. Housekeeping change to keep CAD assets and example image in sync and remove stale lock file.
    [backplate.0002.ipt, backplate.ipt]
2026-05-10 Added STEP files
    [1x1_asm_main.0007.iam, 1x1_asm_main.0008.iam, 1x1_asm_main.iam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]

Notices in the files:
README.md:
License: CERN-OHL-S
